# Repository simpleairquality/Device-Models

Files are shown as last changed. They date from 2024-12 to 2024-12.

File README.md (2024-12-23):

# Device Models

## SimpleAQ Pro

A primary goal while crafting the chassis for the AQ Pro was to have the fewest separate parts needed and a minimal hardware count. To accomplish this all the hardware, _with the exception of the RaspberryPi and custom TopHat_, simply friction fit into the Base Holder with only a light push of a finger. The end result is a chassis that only requires two (2) sperate parts, the Base Holder and Chassis Shell. Additionally, it incorporates two screw mounts on the back side that fit standard drywall or wood screws to allow the AQ Pro to be mounted to whatever surface is needed.

The total hardware needed to assemble the AQ Pro is as such:

- Four (4) M3x8mm Screws
- Four (4) M2.5x10mm Standoffs Make to Female
- Four (4) M.2.5x6mm Screws
- _Optional_ Two (2) Drywall Screws

The next goal was to make everything 3D Printable with minimal supports, if any, that used the least amount of material while maintaining structural rigidity and weather resistance. The final chassis can be printed in about four hours and uses less than 150g of material while needing supports on only one area of the model. 

It should be noted that a material choice of PETG, ASA, ABS, or similar is required for outdoor use. PLA will not hold up to environmental stresses.

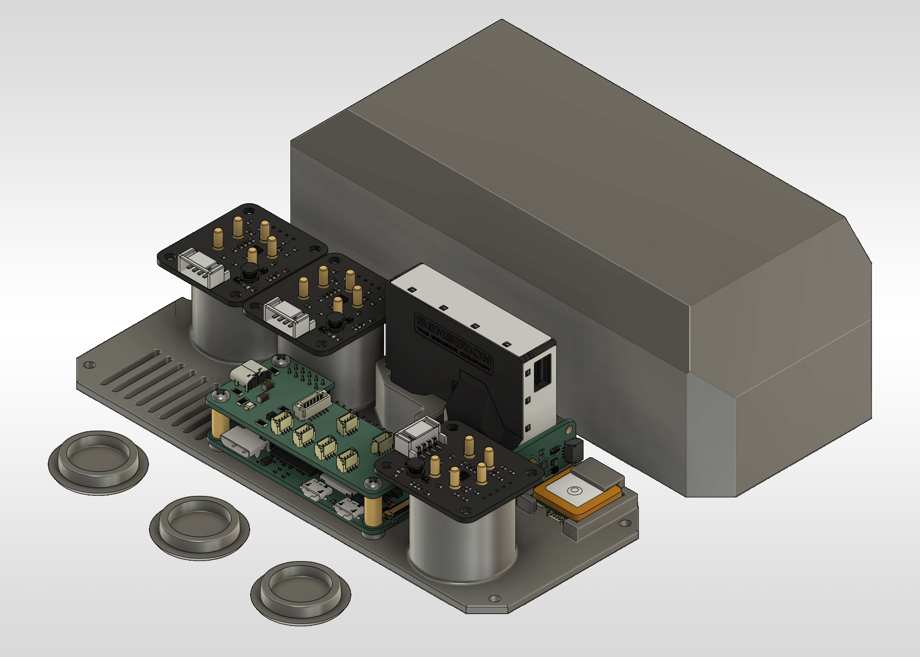
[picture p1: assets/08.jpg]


## Hardware Install Guide

Below are the recommended steps to assemble your own SimpleAQ Pro Device

### Step One - The Base

Take the Base Holder and place onto your work surface, inspect it for any defects, damage, or print errors.

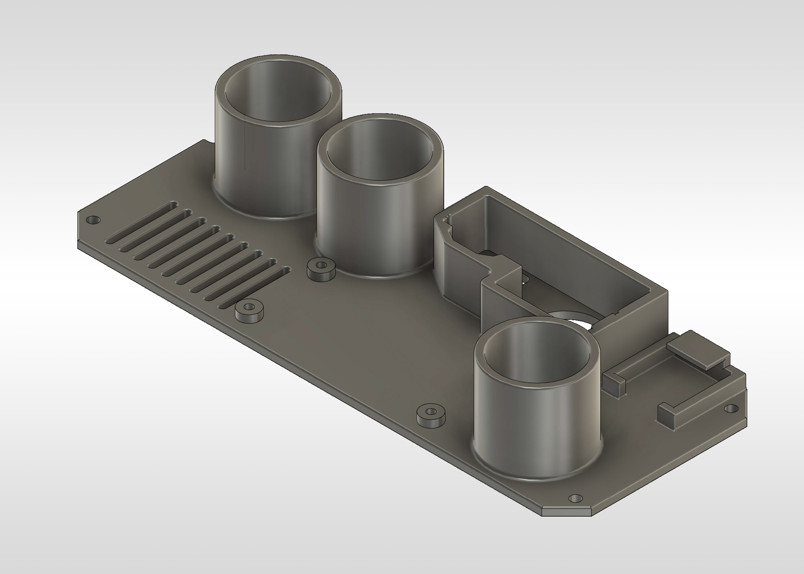
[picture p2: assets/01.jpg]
Base Holder with nothing installed in it


### Step Two - The GPS

Slide the BE-180 GPS into its housing area ensuring the connector is on the bottom side. It is recommended to the connect the cable to the GPS before installing the GPS.

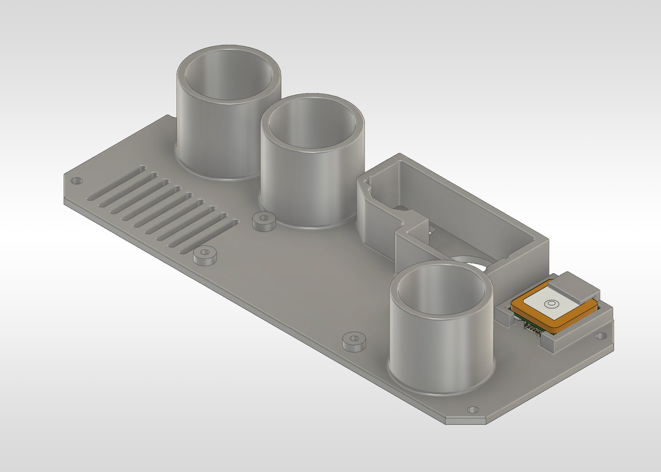
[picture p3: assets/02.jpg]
GPS Install


### Step Three - The BMP

Press the BMP into the slot next to the GPS with the _BMP Text_ on the module facing up to avoid damaging any components on the board. It's a tight fit, but won't damage anything while installing. Again, it is recommended to the connect the cable to the BMP before installing it.

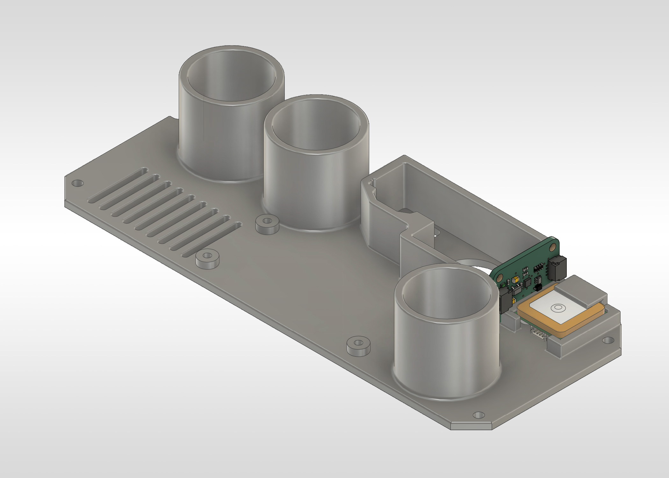
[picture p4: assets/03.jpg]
BMP Install


### Step Four - The SENS

Next insert the SENS module into its dedicated location making sure it's fully seated. Cable installation can be done now or later.

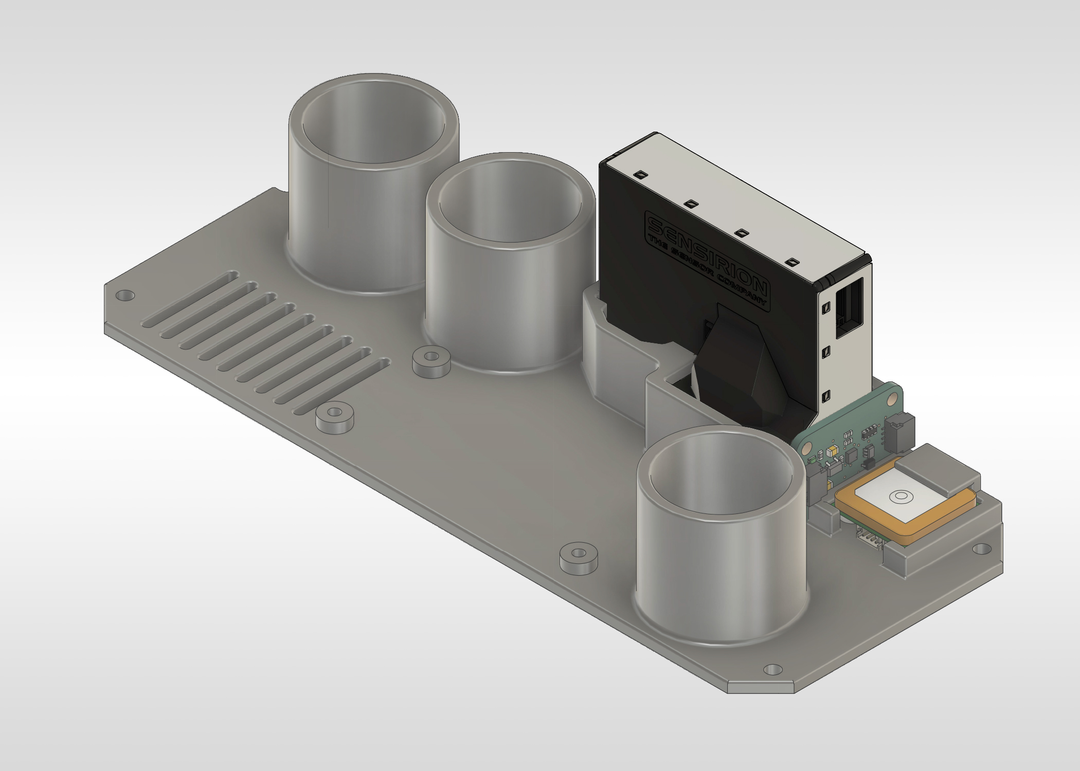
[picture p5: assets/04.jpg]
SENS Install


### Step Five - The RaspberryPi Zero

Gather the RaspberryPi Zero and four standoffs. Place the Pi with the Micro SD card slot closest to the grille vents. Secure it to the Base Holder with the four stand offs.

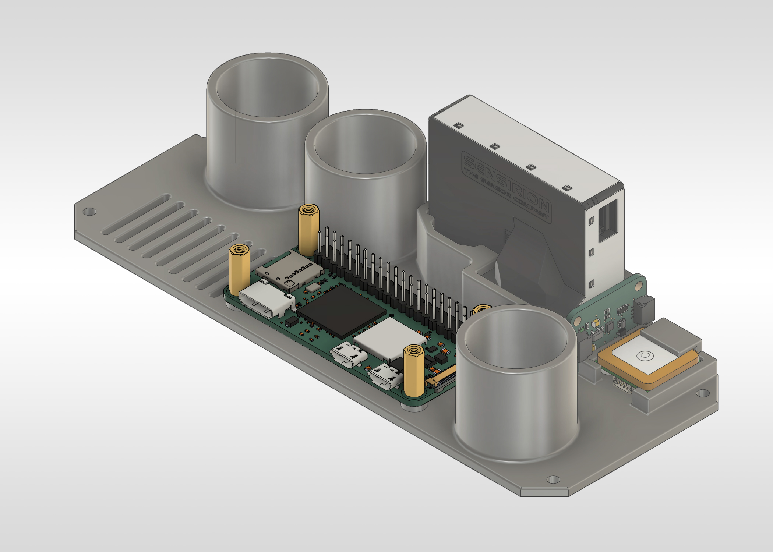
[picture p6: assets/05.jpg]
rPi Install


### Step Six - TopHat

Now attach the TopHat onto the RaspberyPi with the power connector over the Pi's SD Card Slot. Secure it with four M2.5 screws.

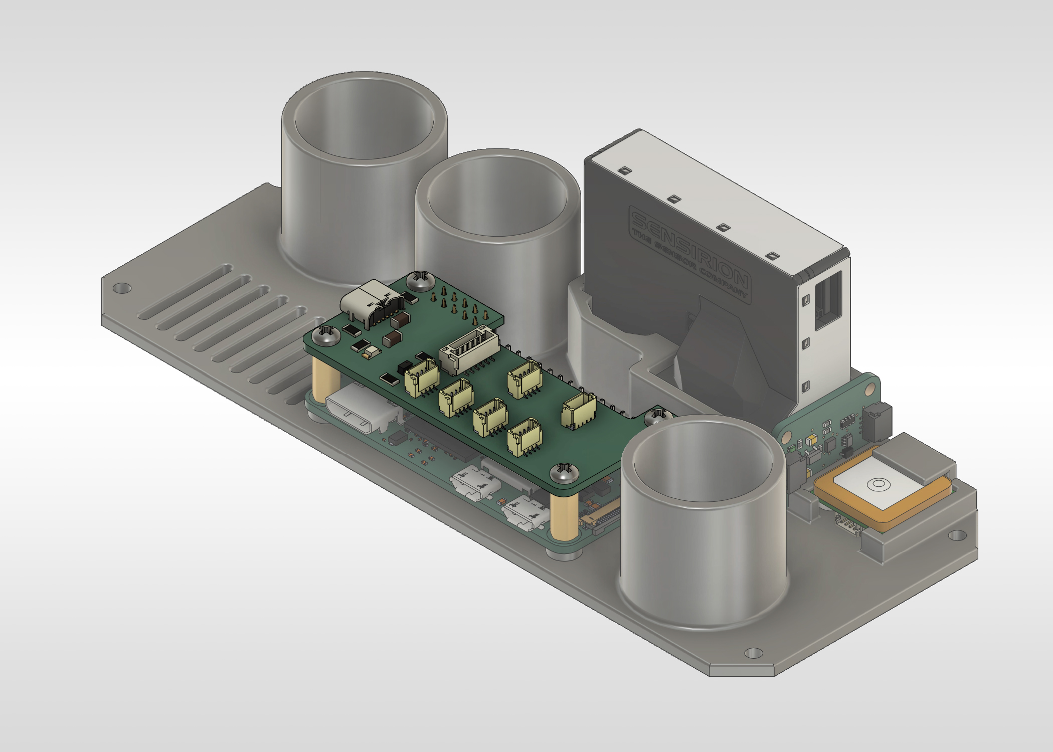
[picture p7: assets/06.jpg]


### Step Seven - Specialty Sensors

If you are using any specialty sensors press fit them into the included tube slots. Use which ever locations you prefer. 
_If you have less than three sensors use the AQ Pro Plugs to seal off the unused tubes._

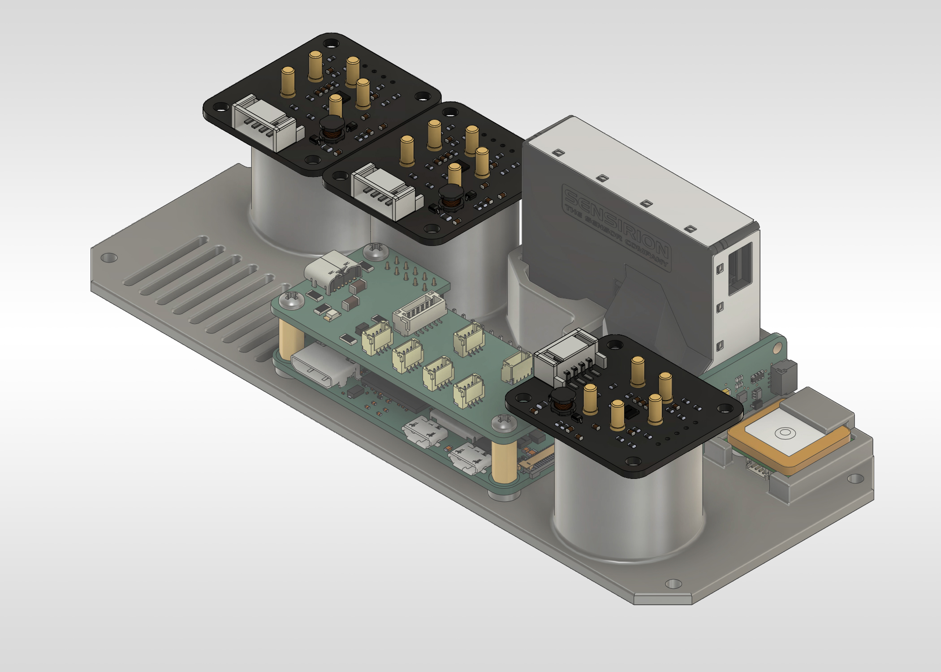
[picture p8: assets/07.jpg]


### Step Eight - Connect Everything and Close it up

Connect everything to the TopHat following the labeles on the TopHat. Plug in the power cable to the TopHat and route the cable through the included notch of the Base Holder. Flip the Base Holder over and insert it into the Chassis Shell ensuring the SENS is closest to the wall mounting screws of the Chassis Shell. Secure the Base Holder to the Chassis Shell with four M3x8mm Screws.

And your done!

## 3D Printable Files

Below are the files needed to print your own SimpleAQ Pro

[Base Holder](https://github.com/simpleairquality/Device-Models/blob/main/assets/Base%20Holder.step)<br/>
[Chassis Shell](https://github.com/simpleairquality/Device-Models/blob/main/assets/Chassis%20Shell.step)<br/>
[Chassis Plug](https://github.com/simpleairquality/Device-Models/blob/main/assets/Plug.step)<br/>

## 3D Printing Notes - Read if you plan to print your own Chassis

- As stated above you must use PETG, ASA, ABS or similar materials if you plan to use the Simple AQ Pro outdoors.
- When printing use 3 or 4 wall loops for strength and weather resistance.
- For infill you can use 15% with any method you prefer.
- Print the Chassis Shell with the top portion on the print bed. It should look like a bowl in the slicing software. No supports are needed for the Shell.
- When printing the Base Holder supports are needed for the GPS Holder. You can use default support settings without issue. See below for the exact area supports are needed.

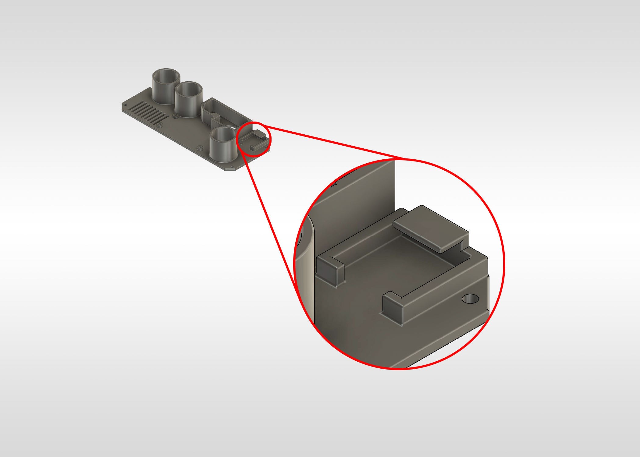
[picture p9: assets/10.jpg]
Support Location


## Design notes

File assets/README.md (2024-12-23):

A folder to house all the files pertaining to the different chassis models.

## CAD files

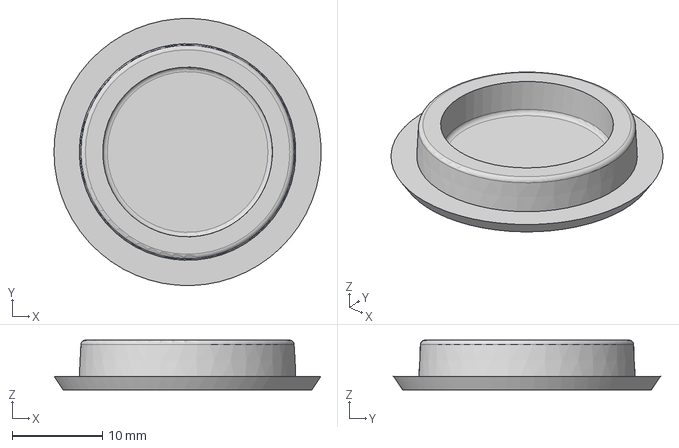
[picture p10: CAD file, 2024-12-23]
assets/Plug.step
29.6 x 29.6 x 5.50 mm

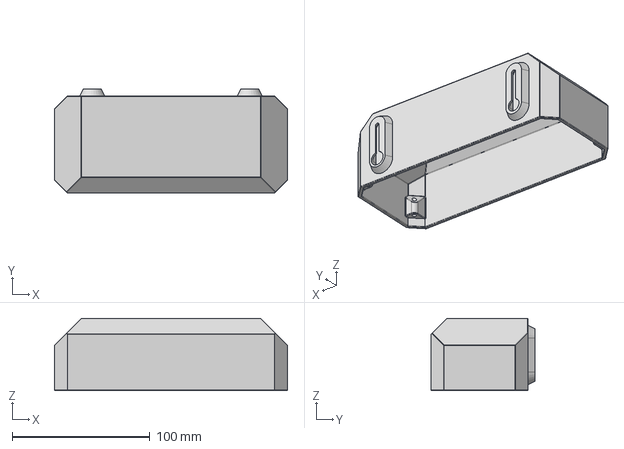
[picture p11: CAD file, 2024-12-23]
assets/Chassis Shell.step
169.1 x 75.6 x 52.4 mm

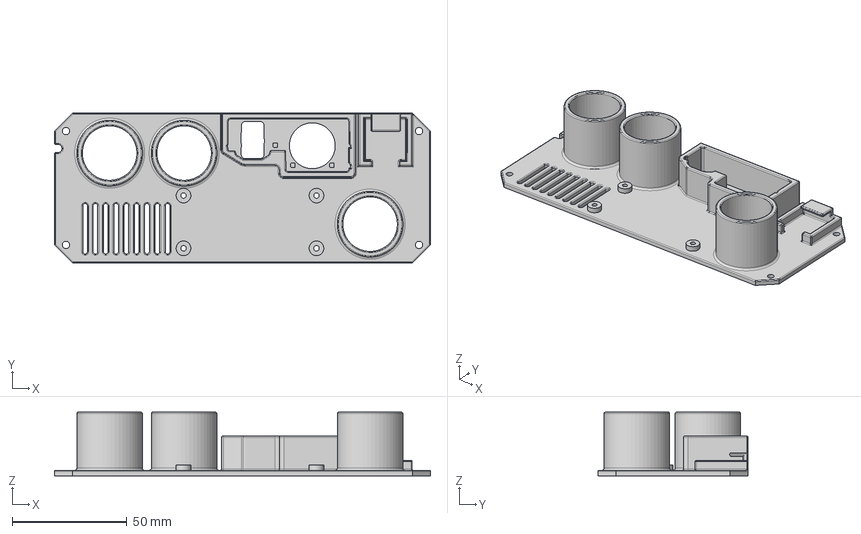
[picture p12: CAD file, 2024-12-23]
assets/Base Holder.step
164.0 x 65.5 x 27.8 mm

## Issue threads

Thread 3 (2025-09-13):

Difficulty in Mounting to Wall using the Screws and Drilling Template.

theGOTOguy, 2025-09-13:
The keyhole slots on the back of the monitor require too much precision for easy installation.

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

The two screws require precision placement – spacing and height.

Even when the screws are installed in a board on the bench, it is difficult to get the monitor on the screws.  Very difficult to get the screw spacing precise on a ladder with one hand. Wood grain and aggregate in mortar or brick make it impossible.

The height of the countersink screws must be adjusted several times to get them just right. Too low, the monitor will not connect. Too high, the monitor wobbles and is not secure.

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

Slipping the monitor on the screws requires two hands to maintain the monitor level so the spacing of the screws matches the spacing of the keyhole slots.  If the monitor tilts just a little, the monitor binds on the screws and is difficult to move up or down. The polymer has high friction so recovering from a jamb requires significant force.

The keyhole slots are subject to breaking.

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

This damage occurred on the demo case and on the case of a resident’s monitor.

The demo case was only slipped on and off the screws in the prepared board.

How can one use the case with such a break?

The internal components are against the back wall of the case limiting the location of screws for attaching a mending plate.

Mounting the monitor on the screws requires a flat surface over 1.5 inches above the screws.  This should be included on the drilling template. Narrow lap siding or moldings may be overlooked without this extra flat space being designated on the template. I have provided three boards with installed screws to aid in attaching the monitor to a wall.

Possible Improvement
1.      The keyhole slots provide a polished interior installation. But required too much precision for exterior installation. What is the height of the screws.
2.      A flange or tabs around the back wall of the monitor with several holes for screws.
Use the holes in the flange to guide the drilling of the wall. Tighten the screws to the flange.
3.      Attaching metal or plastic plates or brackets to the back or side walls. This would provide flexibility for adjusting to the location of the wall screws. Tighten the screws to the brackets.

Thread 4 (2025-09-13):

Research Lower Profile Power Supply

theGOTOguy, 2025-09-13:
The USB-C Power Supply and Cord will not fit into an exterior weatherproof outlet bubble cover.

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

A variety of C-to-C right angle adapters are available that will allow the USB Power Block to be used inside the bubble cover.

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

Dealing with other cords in the outlet could limit their use.

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

Adding a bubble cover to an existing outlet may have to address interference with siding.

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

Possible Improvement
If the dimensions of the outlet bubble covers are standardized and all the same size, choose a combination for power supply and cord plug that will fit. The direction of the receptacle and the cord plug must be selected to fit in the box cover.

1.      Use a cord with a 90-degree bend on the plug.

2.      Choose a smaller USB power supply.

3.      Be prepared to have the cord exit any port in the cover.

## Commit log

2024-12-23 Add files via upload
    Images and Files for the SimpleAQ Device Models.
    [Base Holder.step, Chassis Shell.step, Plug.step]
2025-06-11 Adds Gerber Files and BOM
